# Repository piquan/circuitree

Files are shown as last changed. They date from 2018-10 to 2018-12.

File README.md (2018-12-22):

# Christmas tree circuit

Merry Christmas!  This is a fun little Christmas decoration that I
created as a gift to friends and family: a small circuit board in the
shape of a Christmas tree, with flashing lights and decorative
buttons, and a stand with has an optional nameplate.

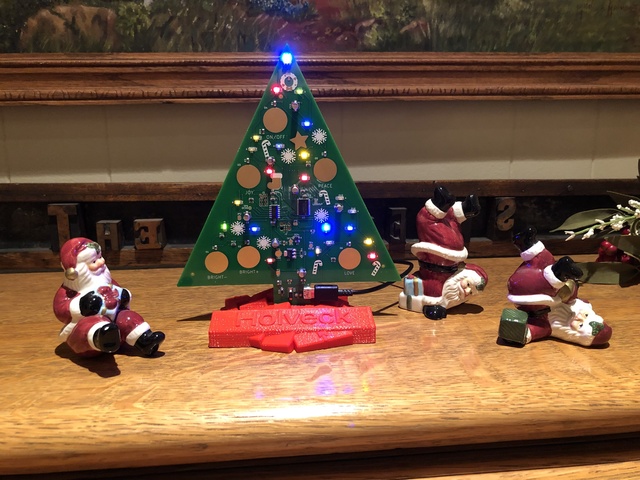
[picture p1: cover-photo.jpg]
Photo of the first production-complete Christmas tree decoration


I designed and programmed this from scratch for my closest friends and
family.  It’s taken me several months of engineering, but it’s been a
lot of fun, and I learned a lot of new things while I built it.  It’s
conceptually inspired by a similar circuit that Dad and I built in the
80s from a magazine article, but this circuit uses completely
different modern technology.  I sent my blueprints to [Macrofab, a
factory in Houston](https://macrofab.com/) to create the circuit
boards, and to [Jinxbot, a one-man 3D printing company in Mountain
View](https://jinxbot.com/) to create the stands.  I hand-programmed
and signed each circuit board.  In the four months I spent creating
this, I went through three revisions of the circuit board (plus
several smaller test designs), four revisions of the stand, and
hundreds of revisions of the program.  I hope you enjoy the Christmas
lights in your home as much as I’ve enjoyed creating it!

# Contributing

The entire project is open-source; you're encouraged to modify and
improve it.  Many of my friends are makers, so I want to make sure
that they can have extra fun by reading the details.  The project is
controlled by an ATtiny84A, so you can edit and upload the code right
from the Arduino IDE!  The firmware, debugging device, schematics, PCB
design, and decorative artwork is all in GitHub.

If you just want to look at the schematics and don't have KiCAD, you
can go to the "releases" tab in GitHub and download a zip file with
PDFs of the schematic and PCB, Gerber files for the PCB, .hex files
for the firmware, and .stl and .png files of the stand.

For technical documentation, visit the wiki.  There are notes there
about design decisions I've made, how to reprogram the Christmas tree,
and other useful information for makers.

Contributions are very welcome!  The best way to contribute is to open
a pull request or issue on GitHub.

# Credits

The schematic, PCB layout, decorative artwork, and firmware were all
designed by Joel Holveck.

The tlc5947.h LED driver controller library was originally written by
Limor Fried/Ladyada for Adafruit Industries, at
<https://github.com/adafruit/Adafruit_TLC5947/>.  The version included
here has several changes to use less memory, because of the needs of
the ATtiny environment.  I used Adafruit products (such as the
[TLC5947 breakout board](https://www.adafruit.com/product/1429)
extensively during the development of this project, and am very
grateful both for their product line and open-source contributions.

The capsense.h capacitive touch sensor library was inspired by the
library created by Paul Bagder as maintained by Paul Stoffregen, at
<https://github.com/PaulStoffregen/CapacitiveSensor/>.  The
implementation here is completely new, but borrows several ideas from
the Badger/Stoffregen library.  The Badger/Stoffregen capacitive touch
library is a very simple, straightforward capacitive touch sensing
library; seeing the way it was used helped convince me that the design
was viable.

# License

This project is copyright 2018 by Joel Ray Holveck.  All rights
reserved.

Different parts of this project are licensed differently; the licenses
are in the individual directories.  Generally, firmware is under
GPLv3, the PCB is under the CERN OHL, and the decorative artwork is
under CC-BY-SA.

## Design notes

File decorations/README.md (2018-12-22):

These are the original SVGs I used to create the decorative artwork on
the PCB.  This includes elements such as the snowflakes, wreath, etc.

Most of the decorations were created as svgs, exported as pngs,
imported to KiCad as mods, and then hand-edited to adjust layers.  I
haven't documented this process yet; please open an issue on GitHub if
you need information on how I did this.

My signature was not silkscreened; I hand-signed each board using a
Sharpie silver paint pen (34968PP).  The area of the PCB I signed was
deliberately cleared of vias (the only gaps in the silkscreen on the
back), so that the paint wouldn't conduct inadvertently.  My own
testing with the paint indicated that it's not conductive, but I still
wanted to avoid possible long-term corrosion or other issues.

The files in this directory are licensed under a Creative Commons
Attribution-ShareAlike 4.0 International License.  To view the
license, please visit http://creativecommons.org/licenses/by-sa/4.0/

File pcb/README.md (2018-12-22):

# PCB files

These are the files for the electrical schematic and PCB.

These files are in KiCAD format.  If you check out this directory, you
should be able to open christmas-tree.pro in KiCAD to see the
schematic and PCB layout.

The decorative artwork (and a few custom footprints) are included in
the christmas-tree.pretty directory.  The original SVG files used to
produce the decorative artwork are in the GitHub repository in the
decorations subdirectory.

If you just want to view the schematics or PCB layout files, they are
available in PDF format in the [release
ZIP](https://github.com/piquan/christmas-tree/releases/download/r4.0/Christmas-Tree-r4.zip).

The bill of materials is not included in my KiCAD files.  The BOM I
actually used is
[in the wiki](https://github.com/piquan/christmas-tree/wiki/Bill-of-materials).
That wiki page also includes a few notes about why I chose particular
components, but I don't yet have full documentation about the
components' design constraints.

# License

Copyright (C) 2018 Joel Ray Holveck.  All rights reserved.

This circuit is licensed under the CERN OHL, version 1.2.  The full
license is available in LICENSE.txt.  If you wish to distribute a
modified design, please update CHANGES.txt accordingly.

The requirements of section 3.1 of the CERN OHL require you to
maintain my original copyright and URL on the silkscreen of the PCB.
If you want a special exemption from these requirements, and your
modified PCB will include a clear traceable path to the original
project, I might approve a change to this text.  (For instance,
forking my GitHub project and changing the URL to your fork is likely
to be okay.)  In this case, contact me to request an excemption.

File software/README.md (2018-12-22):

# Firmware to program and control the Christmas tree circuit

This contains two programs: the christmas-tree subdirectory contains
the actual firmware to be uploaded to the tree; it also contains a
script to upload the firmware and program the fuses.  The spi-slave
subdirectory contains a program used to read the serial debugging I/O
(see the wiki for more details).

Copyright (C) 2018 Joel Ray Holveck

This program is free software: you can redistribute it and/or modify
it under the terms of the GNU General Public License as published by
the Free Software Foundation, either version 3 of the License, or
(at your option) any later version.

This program is distributed in the hope that it will be useful,
but WITHOUT ANY WARRANTY; without even the implied warranty of
MERCHANTABILITY or FITNESS FOR A PARTICULAR PURPOSE.  See the
GNU General Public License for more details.

You should have received a copy of the GNU General Public License
along with this program.  If not, see <https://www.gnu.org/licenses/>.

Additionally, tlc5947.h may also be copied under the terms of the
3-clause BSD license.  The license terms are in that file.

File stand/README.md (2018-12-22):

# Stand

The stand included with this project is 3d-printed, and designed in
OpenSCAD.

Many recipients have households with a common family name; for these,
the stand has a nameplate.  The stands I gave to some recipients (such
as families with children from a previous marriage) do not have
nameplates.  These are all generated from a common OpenSCAD file.

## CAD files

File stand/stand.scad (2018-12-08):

// You can set a name to have a personalized name plaque.  You can also
// set this on the command line with '-Dname="foo"', which will override
// this value.
name="";
bxr=1;                          // Box rounding

module gift(dx, dy, dz, x, y, z, tx, ty, tz, ribbonside=3) {
     // Prevent voids under boxes by extending them to the table.
     // Where this causes visible artifacts, it's best to make the box
     // taller.
     // This is the convex hull formed by (1) the box's bottom surface
     // and (2) the box's bottom surface projected on the xy plane.
     hull() {
          linear_extrude(height=0.1) projection()
               translate([x, y, z+(dz/2)-0.5]) rotate([tx, ty, tz]) hull() {
               translate([dx/2-bxr, dy/2-bxr, -dz/2+bxr]) sphere(r=bxr);
               translate([dx/2-bxr, -dy/2+bxr, -dz/2+bxr]) sphere(r=bxr);
               translate([-dx/2+bxr, dy/2-bxr, -dz/2+bxr]) sphere(r=bxr);
               translate([-dx/2+bxr, -dy/2+bxr, -dz/2+bxr]) sphere(r=bxr);
          }
          translate([x, y, z+(dz/2)-0.5]) rotate([tx, ty, tz]) hull() {
               translate([dx/2-bxr, dy/2-bxr, -dz/2+bxr]) sphere(r=bxr);
               translate([dx/2-bxr, -dy/2+bxr, -dz/2+bxr]) sphere(r=bxr);
               translate([-dx/2+bxr, dy/2-bxr, -dz/2+bxr]) sphere(r=bxr);
               translate([-dx/2+bxr, -dy/2+bxr, -dz/2+bxr]) sphere(r=bxr);
          }
     }
     translate([x, y, z+(dz/2)-0.5]) rotate([tx, ty, tz]) {
          // Box
          //cube([dx, dy, dz], center=true);
          // We actually use the hull of spheres for the box to prevent
          // lots of sharp 90deg corners.
          hull() {
               translate([dx/2-bxr, dy/2-bxr, dz/2-bxr]) sphere(r=bxr);
               translate([dx/2-bxr, dy/2-bxr, -dz/2+bxr]) sphere(r=bxr);
               translate([dx/2-bxr, -dy/2+bxr, dz/2-bxr]) sphere(r=bxr);
               translate([dx/2-bxr, -dy/2+bxr, -dz/2+bxr]) sphere(r=bxr);
               translate([-dx/2+bxr, dy/2-bxr, dz/2-bxr]) sphere(r=bxr);
               translate([-dx/2+bxr, dy/2-bxr, -dz/2+bxr]) sphere(r=bxr);
               translate([-dx/2+bxr, -dy/2+bxr, dz/2-bxr]) sphere(r=bxr);
               translate([-dx/2+bxr, -dy/2+bxr, -dz/2+bxr]) sphere(r=bxr);
          }
          // Bow body
          translate([0, 0, dz/2+.25]) hull() {
               translate([-.5, -.5, 0]) sphere(r=0.5);
               translate([-.5, .5, 0]) sphere(r=0.5);
               translate([.5, -.5, 0]) sphere(r=0.5);
               translate([.5, .5, 0]) sphere(r=0.5);
          }
          // Bow ribbons
          bowrot = (ribbonside >= 4 ? 90 : 0);
          rotate([0, 0, bowrot]) translate([0, 0, dz/2]) hull() {
               translate([-2, -2, 0.5]) sphere(r=0.25);
               translate([-2, 2, 0.5]) sphere(r=0.25);
               translate([-2, -2, 0]) sphere(r=0.25);
               translate([-2, 2, 0]) sphere(r=0.25);
               sphere(r=0.5);
          }
          rotate([0, 0, bowrot]) translate([0, 0, dz/2]) hull() {
               translate([2, -2, 0.25]) sphere(r=0.25);
               translate([2, 2, 0.25]) sphere(r=0.25);
               translate([2, -2, 0]) sphere(r=0.25);
               translate([2, 2, 0]) sphere(r=0.25);
               sphere(r=0.5);
          }
          // Box ribbons
          if (ribbonside == 1 || ribbonside == 3 ||
              ribbonside == 5 || ribbonside == 7) {
               hull() {
                    translate([dx/2, .5, dz/2]) sphere(r=0.25);
                    translate([dx/2, -.5, dz/2]) sphere(r=0.25);
                    translate([-dx/2, .5, dz/2]) sphere(r=0.25);
                    translate([-dx/2, -.5, dz/2]) sphere(r=0.25);
                    translate([dx/2, .5, -dz/2]) sphere(r=0.25);
                    translate([dx/2, -.5, -dz/2]) sphere(r=0.25);
                    translate([-dx/2, .5, -dz/2]) sphere(r=0.25);
                    translate([-dx/2, -.5, -dz/2]) sphere(r=0.25);
               }
          }
          if (ribbonside == 2 || ribbonside == 3 ||
              ribbonside == 6 || ribbonside == 7) {
               hull() {
                    translate([.5, dy/2, dz/2]) sphere(r=0.25);
                    translate([.5, -dy/2, dz/2]) sphere(r=0.25);
                    translate([-.5, dy/2, dz/2]) sphere(r=0.25);
                    translate([-.5, -dy/2, dz/2]) sphere(r=0.25);
                    translate([.5, dy/2, -dz/2]) sphere(r=0.25);
                    translate([.5, -dy/2, -dz/2]) sphere(r=0.25);
                    translate([-.5, dy/2, -dz/2]) sphere(r=0.25);
                    translate([-.5, -dy/2, -dz/2]) sphere(r=0.25);
               }
          }
     }
}

// This is an approximation of the desired shape.  Use it with % for debugging.
module approximation() {
     intersection() {
          // This sphere is designed so that it's 100mm at the z=0
          // plane, and 10mm high.  Solving
          // (100/2)^2 + (r-10)^2 = r^2 gives r=130.
          translate([0, 0, -120]) sphere(r=130);
          // Cut it off at the table.
          translate([-51, -51, 0]) cube([102, 102, 20], center=false);
     }
}
//%approximation();

module smallest() {
     // This is a small section to make sure that there aren't
     // critical gaps in the area that prevent it from functioning as
     // a support base.
     intersection() {
          // This sphere is designed so that it's 80mm at the z=0
          // plane, and 8mm high.  Solving
          // (80/2)^2 + (r-8)^2 = r^2 gives r=104.
          translate([0, 0, -96]) sphere(r=104);
          // Cut it off at the table.
          translate([-51, -51, 0]) cube([102, 102, 20], center=false);
     }
}

// Negative elements
module keepout() {
     // A bit of clearance for the board's components etc
     translate([-9, -4, 10]) cube([18, 5, 10], center=false);
}
module slot() {
     // Slot for the board to sit in
     translate([0, 0, 8]) cube([26.75, 2, 20], center=true);
}
module table() {
     // Flat bottom for the table or other surface
     translate([-100, -100, -50]) cube([200, 200, 50], center=false);
}
module usbchan() {
     // Channel for the USB connector.  Assume the USB shroud goes 2mm
     // on either side of the connector's footprint edge.  The
     // connector is 14mm from the bottom of the board, which is
     // 2mm from the table (see slot_struts).  That means the channel
     // starts 14mm from the table.
     // The connector is 9mm wide, so with margins use 13mm.
     translate([10, -4, 14]) {
          cube([60, 8, 13]);
     }
}
%usbchan();

module slot_struts() {
     // Small struts along the bottom for the board to sit on
     // If you move these, fix usbchan() accordingly.
     translate([-5, 0, 1]) cube([2, 3, 2], center=true);
     translate([5, 0, 1]) cube([2, 3, 2], center=true);
}

module gifts() {
     scale(1.2) {
          //   SIZE                POSITION            ROTATION
          gift(21, 19, 5,          10, 10, 2.5,        5, 10, 15,     0);
          gift(19, 20, 6,          8, -11, 3,          10, 5, 0,      5);
          gift(13, 8, 5,           -13, 5, 4,          -5, -10, 15,   2);
          gift(12, 12, 5,          -8, 17, 4,          -5, -5, -5,    8);
          gift(17, 17, 6,          -10, -12, 5,        10, -15, -12,  3);
          gift(8, 12, 8,           2, 18, 4,           -20, -15, 10,  6);
          gift(24, 6, 3,           20, 1, 4,           -20, 15, 10,   2);
          gift(15, 20, 2,          -25, -8, 3,         15, -15, 5,    3);
          gift(16, 19, 7,          -22, 10, 2.5,       -15, -15, 5,   4);
          gift(21, 17, 8,          -20, -25, -1,        15, -10, -35,  6);
          gift(10, 25, 6,          -35, 0, 1,          0, -20, 10,    2);
          gift(12, 20, 3,          30, -15, 2.5,       5, 10, -20,    8);
          gift(15, 15, 5,          20, -10, 6,         5, 10, 60,     0);
          gift(20, 20, 3,          13, -22, 6,         10, 10, 10,    6);
          gift(30, 10, 7,          15, -35, 0,         15, -5, 15,    2);
          gift(15, 25, 6,          -5, -30, 2,         15, -5, -20,   8);
          gift(20, 10, 4,          -5, 10, 10,         10, -5, -45,   3);
          gift(20, 10, 3,          30, 15, 2,          -20, 5, -45,   5);
          gift(11, 16, 4,          25, 12, 5,          0, 15, 35,     2);
          gift(11, 26, 6,          12, 24, 3,          -20, 5, -5,    8);
          gift(14, 14, 6,          34, 0, 1,           -10, 25, 0,    0);
          gift(24, 8,  8,          0, 34, 1,           -25, -10, 0,   5);
          gift(17, 13, 4,          0, 24, 5,           -20, -5, 10,   2);
          gift(19, 20, 6,          -19, 22, 3,         -35, -5, 40,   8);
          gift(15, 15, 8,          25, 28, 0,          0, 0, 45,      4);
          gift(10, 15, 8,          -32, -16, 0,        0, 0, 30,      4);
          gift(15, 10, 8,          -32, 20, 0,         0, 0, 30,      2);
     }
}
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

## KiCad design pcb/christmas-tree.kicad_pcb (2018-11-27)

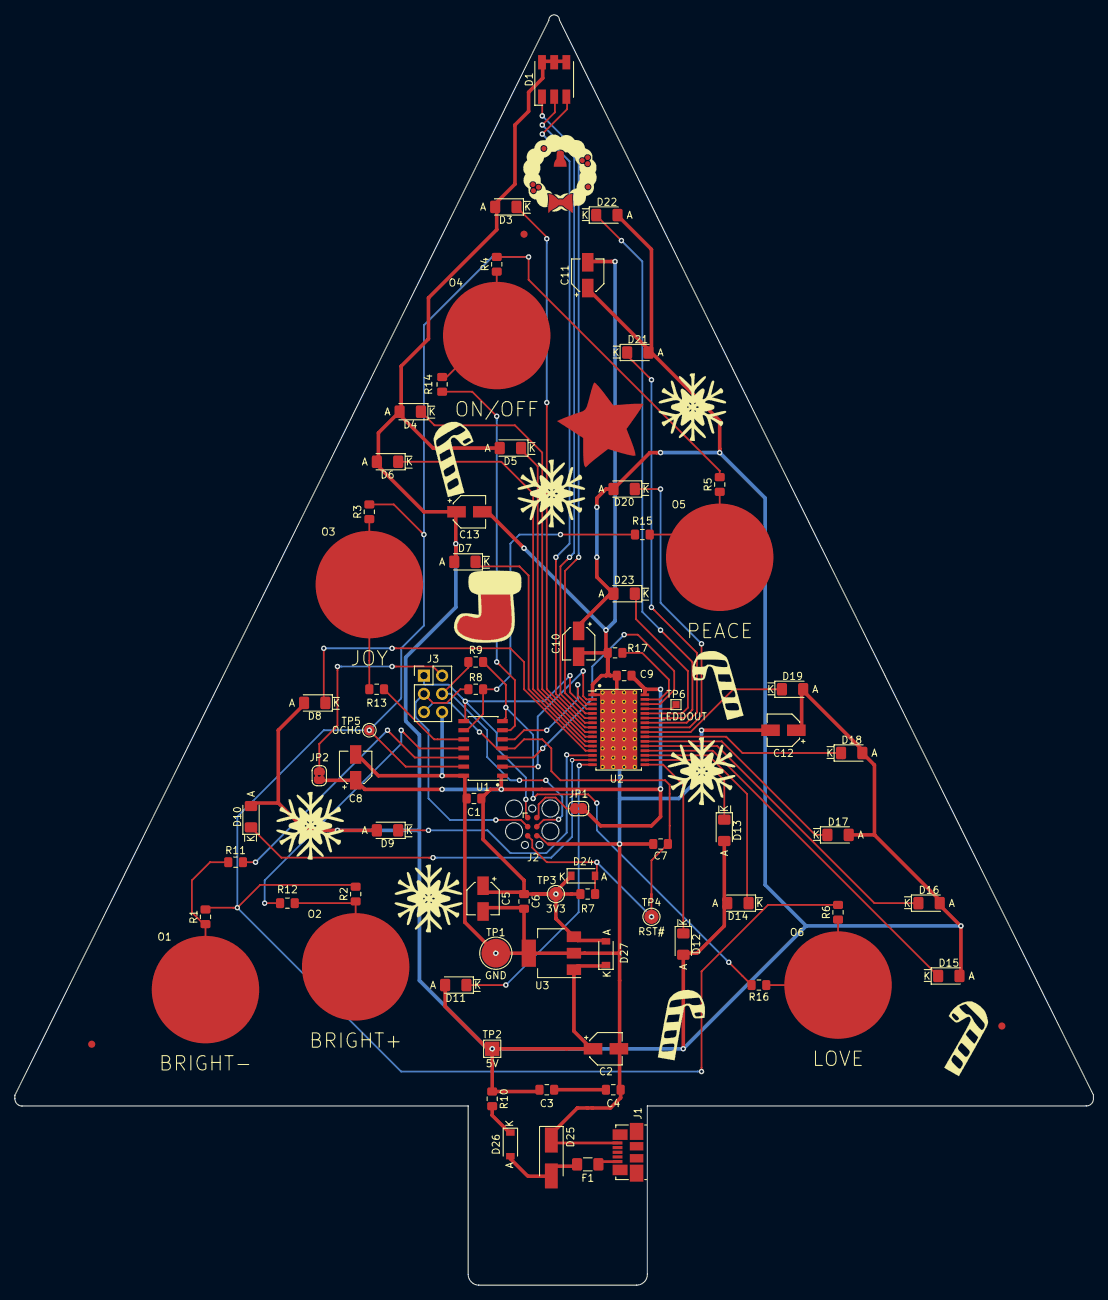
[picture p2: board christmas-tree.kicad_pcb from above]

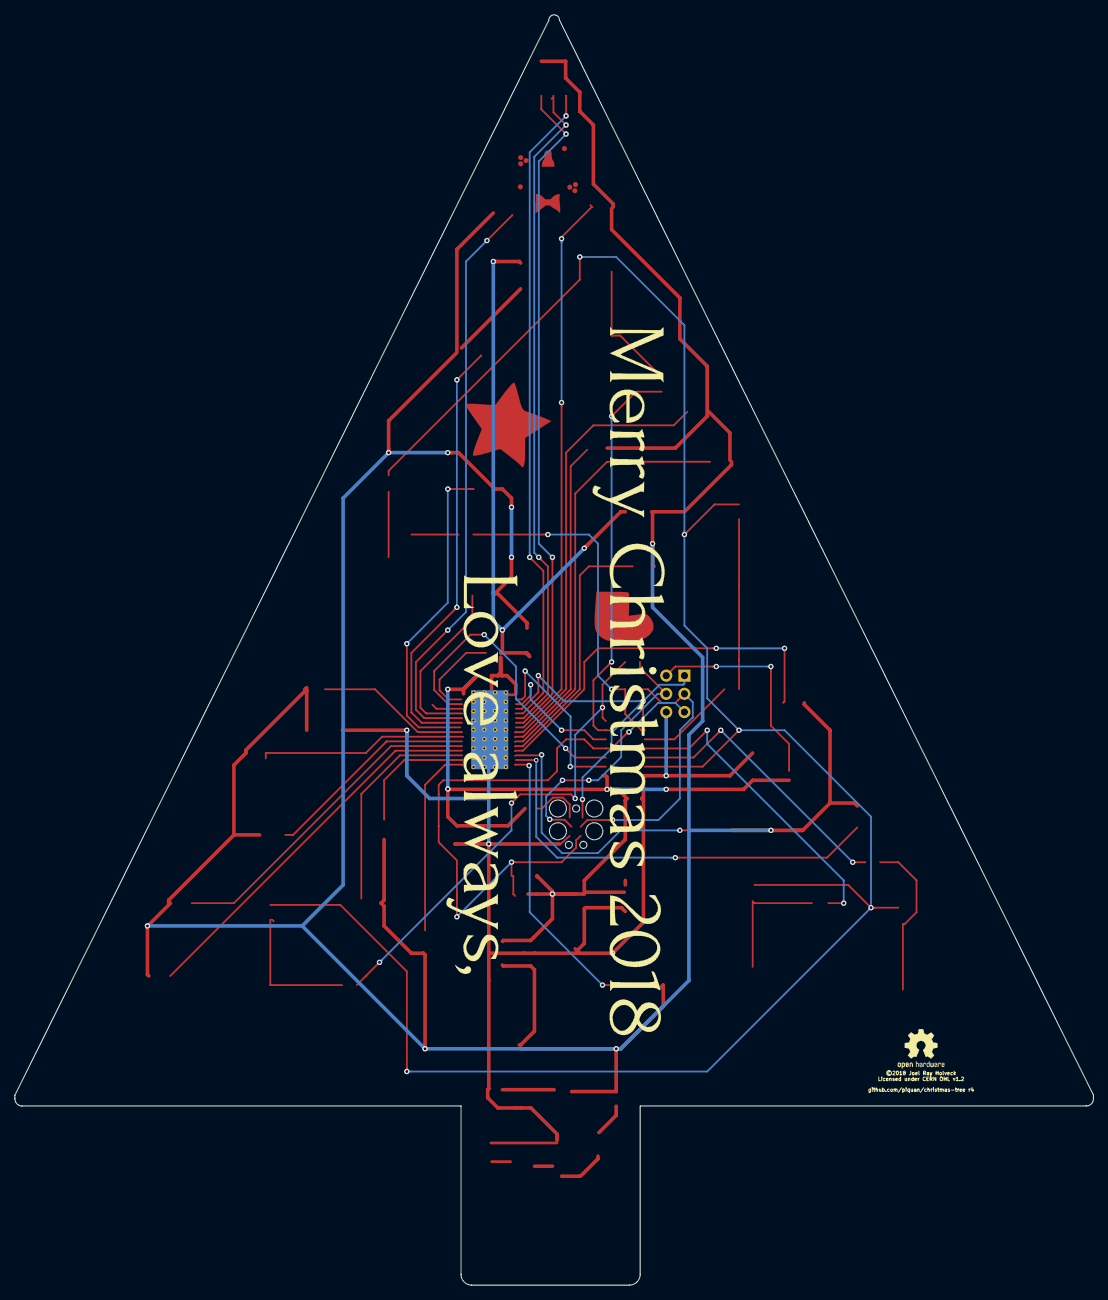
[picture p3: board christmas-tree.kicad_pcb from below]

Board: 2 copper layers, 150.5 x 177.2 mm, 95 parts (3 on the bottom side), 55 nets.

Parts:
C1, C9: 0.1uF; C_0805_2012Metric_Pad1.15x1.40mm_HandSolder
C2, C5, C8, C10, C11, C12, C13: 3.3uF; CP_Elec_4x5.4
C3, C4, C6, C7: DNP; C_0805_2012Metric_Pad1.15x1.40mm_HandSolder
D1: LED_RGB; LED_RGB_5050-6
D3, D7, D11, D15, D19, D23: LTST-C150KRKT; LED_1206_Wurth_AK
D4, D8, D12, D16, D20: LTST-C150KSKT; LED_1206_Wurth_AK
D5, D9, D13, D17, D21: LTST-C150TBKT; LED_1206_Wurth_AK
D6, D10, D14, D18, D22: LTST-C150KGKT; LED_1206_Wurth_AK
D24, D26: MBR0520L; D_SOD-123_AK
D25: SMAJ7.0CA; D_SMA_Handsoldering
D27: DNP; D_SOD-123_AK
DORN1: SYM_Arrow45_Tiny; star
DORN2: SYM_Arrow45_Tiny; stocking
DORN3, DORN5: SYM_Arrow45_Tiny; candy-cane
DORN4, DORN6: SYM_Arrow45_Tiny; candy-cane-mirror
DORN7, DORN8, DORN9, DORN10, DORN11: SYM_Arrow45_Tiny; snowflake
DORN12: SYM_Arrow45_Tiny; OSHW-Logo2_7.3x6mm_SilkScreen
DORN13: SYM_Arrow45_Tiny; wreath
F1: 500mA; Fuse_1206_3216Metric_Pad1.42x1.75mm_HandSolder
FID1, FID2, FID3: SYM_Arrow45_Tiny; Fiducial_1mm_Dia_2.54mm_Outer_CopperTop
J1: USB_B_Micro; USB_Micro-B_Molex_47346-0001
J2: TC2030; Tag-Connect_TC2030-IDC-FP_2x03_P1.27mm_Vertical
J3: AVR-ISP-6; PinHeader_2x03_P2.54mm_Vertical
JP1: JCPWR; SolderJumper-2_P1.3mm_Bridged2Bar_RoundedPad1.0x1.5mm
JP2: ISPPWR; SolderJumper-2_P1.3mm_Bridged2Bar_RoundedPad1.0x1.5mm
LOGO1: Logo_Merry_Christmas; merry-christmas
LOGO2: Logo_Merry_Christmas; love-always
O1: BRIGHT-; TestPoint_Pad_D15.0mm
O2: BRIGHT+; TestPoint_Pad_D15.0mm
O3: JOY; TestPoint_Pad_D15.0mm
O4: ON/OFF; TestPoint_Pad_D15.0mm
O5: PEACE; TestPoint_Pad_D15.0mm
O6: LOVE; TestPoint_Pad_D15.0mm
R1, R2, R3, R4, R5, R6: 1M; R_0805_2012Metric_Pad1.15x1.40mm_HandSolder
R7: 10K; R_0805_2012Metric_Pad1.15x1.40mm_HandSolder
R8, R9: 100; R_0805_2012Metric_Pad1.15x1.40mm_HandSolder
R10: 0; R_0805_2012Metric_Pad1.15x1.40mm_HandSolder
R11, R12, R13, R14, R15, R16: 50; R_0805_2012Metric_Pad1.15x1.40mm_HandSolder
R17: 2.7K; R_0805_2012Metric_Pad1.15x1.40mm_HandSolder
TP1: GND; TestPoint_Pad_D4.0mm
TP2: 5V; TestPoint_Pad_2.0x2.0mm
TP3: 3V3; TestPoint_Pad_D2.0mm
TP4: RST#; TestPoint_Pad_D2.0mm
TP5: OCHG; TestPoint_Pad_D1.5mm
TP6: LEDDOUT; TestPoint_Pad_1.0x1.0mm
U1: ATtiny84A-20SSU; SOIC-14_3.9x8.7mm_P1.27mm
U2: TLC5947DAP; HTSSOP-32-1EP_6.1x11mm_P0.65mm_EP5.2x11mm_Mask4.11x4.36mm_T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
U3: LT1129CST-3.3; SOT-223-3_TabPin2

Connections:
+3V3: C1.2, C5.1, C6.1, C8.1, C9.2, D24.1, D27.2, JP1.1, JP2.1, R7.1, TP3.1, U1.1, U2.32, U3.3
+5V: C2.1, C3.1, C10.1, C11.1, C12.1, C13.1, D1.4, D1.5, D1.6, D3.2, D4.2, D5.2, D6.2, D7.2, D8.2, D9.2, D10.2, D11.2, D12.2, D13.2, D14.2, D15.2, D16.2, D17.2, D18.2, D19.2, D20.2, D21.2, D22.2, D23.2, D27.1, R10.1, TP2.1, U3.1
/BLANK: U1.2, U2.2
/IREF: R17.1, U2.31
/ISPMOSI: J2.4, J3.4, R9.1
/ISPSCK: J2.3, J3.3, R8.1
/LEDCLK: U1.5, U2.3
/LEDDOUT: TP6.1, U2.29
/MISO: J2.1, J3.1, U1.8, U2.4
/MOSI: R9.2, R16.2, U1.7
/O1S: R11.2, U1.12
/O2S: R12.2, U1.11
/O3S: R13.2, U1.10
/O4S: R14.2, U1.6
/OCHG: R1.2, R2.2, R3.2, R4.2, R5.2, R6.2, TP5.1, U1.13
/RST#: C7.1, D24.2, J2.5, J3.5, R7.2, TP4.1, U1.4
/SCK: R8.2, R15.2, U1.9
/XLAT: U1.3, U2.30
GND: C1.1, C2.2, C4.2, C5.2, C6.2, C7.2, C8.2, C9.1, C10.2, C11.2, C12.2, C13.2, D25.1, J1.5, J2.6, J3.6, R17.2, TP1.1, U1.14, U2.1, U2.33, U3.2
unnamed: C3.2, C4.1
unnamed: D1.1, U2.5
unnamed: D1.2, U2.6
unnamed: D1.3, U2.7
unnamed: D3.1, U2.8
unnamed: D4.1, U2.9
unnamed: D5.1, U2.10
unnamed: D6.1, U2.11
unnamed: D7.1, U2.12
unnamed: D8.1, U2.13
unnamed: D9.1, U2.14
unnamed: D10.1, U2.15
unnamed: D11.1, U2.16
unnamed: D12.1, U2.17
unnamed: D13.1, U2.18
unnamed: D14.1, U2.19
unnamed: D15.1, U2.20
unnamed: D16.1, U2.21
unnamed: D17.1, U2.22
unnamed: D18.1, U2.23
unnamed: D19.1, U2.24
unnamed: D20.1, U2.25
unnamed: D21.1, U2.26
unnamed: D22.1, U2.27
unnamed: D23.1, U2.28
unnamed: D25.2, D26.2, F1.1
unnamed: D26.1, R10.2
unnamed: F1.2, J1.1
unnamed: J2.2, JP1.2
unnamed: J3.2, JP2.2
unnamed: O1.1, R1.1, R11.1
unnamed: O2.1, R2.1, R12.1
unnamed: O3.1, R3.1, R13.1
unnamed: O4.1, R4.1, R14.1
unnamed: O5.1, R5.1, R15.1
unnamed: O6.1, R6.1, R16.1

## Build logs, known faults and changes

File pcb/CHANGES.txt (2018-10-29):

If you wish to change and redistribute a product based on this design, please modify this file in the modified distribution describing your changes.

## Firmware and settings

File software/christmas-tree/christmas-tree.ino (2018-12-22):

// christmas-tree.ino - Firmware for a Christmas decoration
// Copyright (C) 2018 Joel Ray Holveck
//
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

//#define NDEBUG 1

#include <avr/boot.h>
#include <avr/wdt.h>
#include <EEPROM.h>

#pragma GCC diagnostic warning "-Wall"
#pragma GCC diagnostic warning "-Wextra"

#ifdef NDEBUG
#define assert(e) do {} while (0)
#else
void AssertFail(int lineno);
#define assert(e) ((e) ? (void)0 : AssertFail(__LINE__))
#endif

// I could make this inherit from Print to get printf, etc.  But the
// decimal print routines take up too much flash space (about 300
// bytes), so I print in hex, which is much cheaper.
class CTDebugger final {
#ifdef NDEBUG
 public:
  void write(uint8_t) {}
  template<typename T> void print(T) {}
  template<typename T> void println(T) {}
#else
 private:
  const char hexdigs[16] = {'0', '1', '2', '3', '4', '5', '6', '7',
                            '8', '9', 'a', 'b', 'c', 'd', 'e', 'f'};
  void PrintByte(uint8_t val) {
    write(hexdigs[val >> 4]);
    write(hexdigs[val & 0x0f]);
  }
 public:
  void write(uint8_t);
  void print(uint8_t val) {
    PrintByte(val);
  }
  void print(uint16_t val) {
    PrintByte(val >> 8);
    PrintByte(val);
  }
  void print(uint32_t val) {
    PrintByte(val >> 24);
    PrintByte(val >> 16);
    PrintByte(val >> 8);
    PrintByte(val);
  }
  void print(const char* val) {
    while (*val) {
      write(*(val++));
    }
  }
  void print(int8_t val) {
    if (val < 0) {
      write('-');
      print(static_cast<uint8_t>(-val));
    } else {
      print(static_cast<uint8_t>(val));
    }
  }
  void print(int16_t val) {
    if (val < 0) {
      write('-');
      print(static_cast<uint16_t>(-val));
    } else {
      print(static_cast<uint16_t>(val));
    }
  }
  void print(int32_t val) {
    if (val < 0) {
      write('-');
      print(static_cast<uint32_t>(-val));
    } else {
      print(static_cast<uint32_t>(val));
    }
  }
  void print(float val);
  void print(double val) { print(static_cast<float>(val)); }
  void println() {
    write('\r');
    write('\n');
  }
  template<typename T> void println(T val) {
    print(val);
    println();
  }
 private:
  void Clock(bool val);
#endif
} Debugger;

//#define DO_TRACE 1
#ifdef DO_TRACE
#define TRACELINE(arg) do {                             \
    Debugger.write('t'); Debugger.println(__LINE__);    \
  } while (0)
#else
#define TRACELINE(arg) do {} while (0)
#endif

#include "capsense.h"
#include "tlc5947.h"

// This is smaller than the built-in memset.
void MyMemSet(void* addr, uint8_t size, uint8_t val) {
  for (uint8_t i = 0; i < size; i++) {
    static_cast<char*>(addr)[i] = val;
  }
}

// The Arduino doesn't have a built-in random float function, so I
// have this instead.  It ain't perfect by a long shot, but it works
// for my needs.
float RandomFloat(float max) {
  return (max * static_cast<float>(random()) / static_cast<float>(LONG_MAX));
}

constexpr uint16_t kNumGpios = 10;  // Is this in a #defined constant?

constexpr float kBrightChangeRate = 1.0 / 32;

// Note that CANARY takes about 132 bytes.
#define CANARY 1
constexpr uint8_t kStackCanaryVal = 105;
constexpr uint8_t kStackCanarySweepFreq = 64;

// Regarding kCsSamps: Larger is more stable but slower.  The speed
// also depends on the capacitance present; lower capacitance resolves
// more quickly.  With four sensors (well, as of this writing, one
// sensor being probed 4 times), a 1M resistor, and a 3.3v supply,
// kCsSamps=16 samples gives a loop rate of about 42 Hz when there's
// no finger present, and about 20 Hz when all sensors are triggered.
constexpr uint8_t kCsSamps = 16;

// When tuning kCsThres, make sure your hand isn't over the laptop!
constexpr unsigned int kCsThres = kCsSamps * 6;
constexpr unsigned int kCsThrL = kCsThres / 2;
constexpr unsigned int kCsThrH = kCsThres * 3 / 2;

// For mappings between package pin numbers and GPIO pin numbers,
// see http://highlowtech.org/?p=1695 specifically
// http://highlowtech.org/wp-content/uploads/2011/10/ATtiny44-84.png
constexpr uint8_t kPinCsChg = 0;
constexpr uint8_t kPinCsO1S = 1;
constexpr uint8_t kPinCsO2S = 2;
constexpr uint8_t kPinCsO3S = 3;
constexpr uint8_t kPinCsO4S = 7;
constexpr uint8_t kPinCsO5S = 4;
constexpr uint8_t kPinCsO6S = 6;

// We use the same pin for kPinDbgMosi as kPinLedMosi.
// This is the MISO (not MOSI) line on the ICSP header.
constexpr uint8_t kPinDbgMosi = 5;
constexpr uint8_t kPinDbgSclk = 4;

// The debug protocol seems stable at about 100uS hold time in initial
// experiments.  It may be related to the time I spend on the slave
// doing serial writes, since my writes are amplified a lot.  I might
// also try a direct port read in the slave, which is about 25x
// faster.  Note that this is only the hold time for high or low; the
// total clock period is about twice this.  Note that the debug host
// will resync if there's no clock for 10ms, to make sure it doesn't
// get its bits out of phase.
constexpr unsigned int kDbgClkHoldMicros = 250;

constexpr uint8_t kPinLedMosi = 5;
constexpr uint8_t kPinLedSclk = 8;
constexpr uint8_t kPinLedLat = 9;
constexpr uint8_t kPinLedBlank = 10;

constexpr int kPostFailBlinks = 3;

TLC5947<1,                   // Number of drivers
        kPinLedSclk,         // SPI clock pin
        kPinLedMosi,         // SPI data pin
        kPinLedLat> leds;    // Latch pin

#define LED_PHASE1 0
#define LED_PHASE2 1
#define LED_PHASE3 2
constexpr float kLoveStarMaxRamp = 0.75;
constexpr float kPhaseIncrPeace = 0.005;
constexpr float kPhaseIncr = 0.05;
//#define LED_SCHMITT 3
//#define LED_COUNT0 3  // Note that COUNT0 == Q
//#define LED_COUNT1 4
//#define LED_COUNT2 5
//#define LED_COUNT3 6
//#define LED_Q 9
//#define LED_NQ 10
//#define LED_CYCLE 11
//#define LED_CAP 12
#define LED_METER_START 15
constexpr uint16_t kLedMeterCount = 5;
constexpr long kLedMeterMax = kCsThres * 2;

constexpr int kNumLedColors = 4;
// The instance, and the referenced arrays, must be in PROGMEM.
class LedStars {
 private:
  class PgmArrayReader {
   public:
    explicit PgmArrayReader(uint8_t const* pgm_array_ptr)
        : pgm_array_ptr_(pgm_array_ptr) {}
    explicit PgmArrayReader(uint8_t const* const* pgm_array_pgm_ptr)
        : pgm_array_ptr_(pgm_read_word(pgm_array_pgm_ptr)) {}
    uint8_t operator[] (size_t i) const {
      return pgm_read_byte(pgm_array_ptr_ + i);
    }
    PgmArrayReader& operator+=(size_t increment) {
      pgm_array_ptr_ += increment;
      return *this;
    }
   private:
    const uint8_t* pgm_array_ptr_;
  };

 public:
  void Setup() const {
    count_ = pgm_read_byte(&pgm_count_);
  }

  PgmArrayReader by_pos() const {
    return PgmArrayReader(&pgm_by_pos_);
  }
  PgmArrayReader by_color() const {
    return PgmArrayReader(&pgm_by_color_);
  }
  PgmArrayReader color_counts() const {
    return PgmArrayReader(pgm_color_counts_);
  }
  uint8_t Count() const {
    return count_;
  }

 public: // FIXME Make these private
  const uint8_t* pgm_by_pos_;
  const uint8_t* pgm_by_color_;
  const uint8_t pgm_color_counts_[kNumLedColors];
  const uint8_t pgm_count_;
  static uint8_t count_;  // Updated once at start of program
};

uint8_t LedStars::count_;

#ifndef NDEBUG
const uint8_t led_stars_dev_by_pos[] PROGMEM = {
  3, 4, 5, 6, 7, 8, 9, 10, 11, 12, 14, 13, 23, 20, 21, 22 };
const uint8_t led_stars_dev_by_color[] PROGMEM = {
  6, 10, 14, 22,  // green
  3, 7, 11, 23,   // red
  4, 8, 12, 20,   // yellow
  5, 9, 13, 21    // blue
};
constexpr LedStars led_stars_dev PROGMEM = {
  .pgm_by_pos_ = led_stars_dev_by_pos,
  .pgm_by_color_ = led_stars_dev_by_color,
  .pgm_color_counts_ = { 4, 4, 4, 4 },
  .pgm_count_ = 16,
};
#endif
const uint8_t led_stars_norm_by_pos[] PROGMEM = {
  3, 4, 5, 6, 7, 8, 9, 10, 11, 12, 14,
  13, 15, 16, 17, 18, 19, 23, 20, 21, 22 };
const uint8_t led_stars_norm_by_color[] PROGMEM = {
  6, 10, 14, 18, 22,    // green
  3, 7, 11, 15, 19, 23, // red
  4, 8, 12, 16, 20,     // yellow
  5, 9, 13, 17, 21,     // blue
};
constexpr LedStars led_stars_norm PROGMEM = {
  .pgm_by_pos_ = led_stars_norm_by_pos,
  .pgm_by_color_ = led_stars_norm_by_color,
  .pgm_color_counts_ = { 5, 6, 5, 5 },
  .pgm_count_ = 21,
};

#ifndef NDEBUG
const LedStars* led_stars;
#else
constexpr const LedStars* led_stars = &led_stars_norm;
#endif
constexpr int kNumLedStarsMax = led_stars_norm.pgm_count_;

// Constants for Peace and Love modes.
constexpr float kLedStarMinMotion = 0.005;
constexpr float kLedStarDeltaMotion = 0.01;
constexpr long kLedStarPeriod = 64;
constexpr long kLedStarBurstPeriod = 128;

#ifndef NDEBUG
bool dev_mode;
#endif
enum DisplayMode { kModeLove, kModePeace, kModeJoy } display_mode = kModeLove;
enum JoySubMode { kSubModeDoubleChase, kSubModeCylon, kSubModeCylonFill, 
                  kSubModeLast };
JoySubMode joy_sub_mode = kSubModeDoubleChase;

// FIXME Why are these separate from the top-level variables?
struct __attribute__ ((__packed__)) {
  bool uninitialized;  // Erased EEPROM reads as all 1s
  float bright_pct;
  DisplayMode display_mode;
  JoySubMode joy_sub_mode;
} persistent_data;
unsigned long update_persistent_data_at_millis = ULONG_MAX;

// We use the LED on the debugging dongle to tell us if we've ever
// gotten a high reading.  That lets me leave it alone for a long time
// and see if it ever got a false reading.  This tells us if we need
// to send the latch signal.  To prevent spamming the LED latch
// signal, but still let us reset it just by resetting the debug board,
// we only send it at most once per second.
unsigned long debug_led_latch_at_millis;
constexpr unsigned long kDbgLedLatchDelayMs = 1000;

uint16_t bright; // Calculated during startup
float bright_pct = 0.5;

void __attribute__((noinline)) TwinkleBool(uint16_t ledno, bool val) {
  // The twinkling of boolean outputs in debug mode is cute, but it takes
  // 90 bytes or so of code space.
#ifdef DO_TWINKLE_BOOL
  long delta = display_mode == kModeLove ? random(bright/128) : 0;
  // The "16 * delta" is because we totally ignore the gamma curve here.
  leds.setPWM(ledno, val ? bright - (16 * delta) : delta);
#else
  leds.setPWM(ledno, val ? bright : 0);
#endif
}

#ifndef NDEBUG
void __attribute__((noinline)) CTDebugger::Clock(bool val) {
  digitalWrite(kPinDbgSclk, val);
  delayMicroseconds(kDbgClkHoldMicros);
}
void CTDebugger::write(uint8_t byte) {
  pinMode(kPinDbgSclk, OUTPUT);
  for (int i = 0; i < 8; i++) {
    digitalWrite(kPinDbgMosi, byte & 0x80);
    byte <<= 1;
    Clock(true);
    Clock(false);
  }
}

// Takes about 186 bytes (if it's actually called)
void CTDebugger::print(float value_in) {
  union {
    // Essentially defines the IEEE 784-2008 binary16 layout
    struct {
      unsigned int significand: 10;
      unsigned int exponent: 5;
      unsigned int sign: 1;
    } bits;
    float flo;
  } value;
  value.flo = value_in;

  // Print the sign even if it's a NaN.  This saves some code space,
  // and also distinguishes between quiet (negative) and signaling
  // (positive) NaNs.
  if (value.bits.sign) {
    write('-');
  }
  
  // Check NaN and infinity
  if (value.bits.exponent == 0x1f) {
    if (value.bits.significand != 0) {
      print("nan");
    } else {
      print("inf");
    }
    return;
  }
  
  if (value.bits.exponent == 0) {
    write('0');
  } else {
    write('1');
  }
  write('.');

  print(value.bits.significand >> 2);
  print(value.bits.significand << 6);
  
  // We use 'x' to separate the significand from the exponent.  The
  // C++ %a modifier uses 'p', but it prints the exponent in decimal,
  // so we avoid that.
  write('x');
  int8_t norm_exponent = value.bits.exponent - 15;
  print(norm_exponent);
}
#endif

void DidFail(void) {
  // Use this if you want to halt the board after failures (e.g., during
  // overnight testing).
  //wdt_disable();
  //while(1);
}

#ifndef NDEBUG
void AssertFail(int lineno) {
  Debugger.write('A');
  Debugger.println(lineno);
  DidFail();
}
#endif

void PostFail(uint8_t code, uint8_t aux) {
  uint16_t combined_code = (aux << 8) | code;
  for (uint16_t i = 4; i < 20; i++) {
    leds.setPWM(i, combined_code & 1 ? leds.kPwmMax : 0);
    combined_code >>= 1;
  }
  digitalWrite(kPinLedBlank, LOW);

#ifndef NDEBUG
  Debugger.write('\x0c');
  Debugger.write('X');
  Debugger.print(code);
  Debugger.write(':');
  Debugger.println(aux);
  for (uint8_t i = 0; i < kPostFailBlinks; i++) {
    leds.setPWM(1, 0);  // Red LED
    leds.write();
    delay(1000);
    leds.setPWM(1, bright);
    leds.write();
    delay(1000);
  }
#endif
  DidFail();
}

class CapOrnament {
 public:
  CapOrnament(char name, uint16_t sense_pin) :
      cs_(sense_pin), name_(name), sense_pin_(sense_pin) {}
  bool level() const { return state_.level; };
  void set_led_diagnostic(bool d) { state_.led_diagnostic = d; }
  bool led_diagnostic() const { return state_.led_diagnostic; }
  bool offline() const { return state_.offline; }
  void set_offline(bool offline) { state_.offline = offline; }
  void Post(uint8_t code);
  bool SenseEdge();
  bool SenseLevel() { SenseEdge(); return level(); }
  static uint8_t count(void) { return count_; }
#ifndef NDEBUG
  static void SweepDbgSensor();
#endif

 private:
#ifndef NDEBUG
  static constexpr int kDbgSensorPinShift = 1;
  static constexpr uint16_t kDbgSensorSweepLength =
      kNumGpios << kDbgSensorPinShift;
  static uint8_t dbg_sensor_;
#endif
  static uint8_t count_;

  void PostOneWay(uint8_t code, bool value);
#ifndef NDEBUG
  bool Dbg() { return dbg_sensor_ == (sense_pin_ << kDbgSensorPinShift); }
#endif

  template<unsigned int threshold_l, unsigned int threshold_h>
  bool Schmitt(unsigned int input);
  bool CheckRisingEdge(bool input);

  CapacitiveSensor<kPinCsChg> cs_;
  char name_;
  uint8_t sense_pin_;
  struct {
    bool offline : 1;
    bool led_diagnostic : 1;
    bool level : 1;
  } state_;
};
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
void loop() {
  wdt_reset();
  static uint8_t loop_count;
  loop_count++;
#ifndef NDEBUG
  CapOrnament::SweepDbgSensor();
#endif

  bool bright_down_edge = csBrightDn.SenseEdge();
  bool bright_up_edge = csBrightUp.SenseEdge();
  bool bright_down_level = csBrightDn.level();
  bool bright_up_level = csBrightUp.level();
  if (bright_down_level || bright_up_level) {
    if (bright_down_edge)
      bright_pct -= kBrightChangeRate * 3;
    if (bright_down_level)
      bright_pct -= kBrightChangeRate;
    if (bright_up_edge)
      bright_pct += kBrightChangeRate * 3;
    if (bright_up_level)
      bright_pct += kBrightChangeRate;
    UpdateBrightnessFromPct();
    update_persistent_data_at_millis = millis() + 2000;
  }

  bool toggle_onoff = csOnOff.SenseEdge();
  if (toggle_onoff) {
    static bool blank_state = false;
    blank_state = !blank_state;
    digitalWrite(kPinLedBlank, blank_state);
    Debugger.println(blank_state ? 'o' : 'O');
  }

  bool gotLove = csLove.SenseEdge();
  bool gotJoy = csJoy.SenseEdge();
  bool gotPeace = csPeace.SenseEdge();

  // We always reset the display, even if we're in the right mode, to
  // give visual feedback to the user.  Otherwise, the user might
  // start fiddling with buttons by pressing the current mode and
  // think that the button does nothing.
  if (gotLove) {
    display_mode = kModeLove;
  } else if (gotPeace) {
    display_mode = kModePeace;
  } else if (gotJoy) {
    if (display_mode == kModeJoy) {
      joy_sub_mode = 
          static_cast<JoySubMode>(static_cast<int>(joy_sub_mode) + 1);
      if (joy_sub_mode == kSubModeLast) {
        joy_sub_mode = static_cast<JoySubMode>(0);
      }
    }
    display_mode = kModeJoy;
  }

  if (gotLove || gotPeace || gotJoy) {
    MyMemSet(&display_state, sizeof(display_state), 0);
#if 0  // This doesn't work yet
    if (display_mode != kModeJoy) {
      // Filling a float16 with the byte 0x38 works out to about .5;
      // the byte 0x21 is about 0.01.
      static_assert(sizeof(display_state.peace_love.star_brightness) ==
                    sizeof(display_state.peace_love.star_motion),
                    "size mismatch");
      for (uint8_t i = 0;
           i < sizeof(display_state.peace_love.star_brightness);
           i++) {
        static_cast<char*>(static_cast<void*>(&display_state.peace_love.star_brightness))[i] = 0x38;
        static_cast<char*>(static_cast<void*>(&display_state.peace_love.star_motion))[i] = 0x21;
      }
      MyMemSet(&display_state.peace_love.star_ramping_up,
               sizeof(display_state.peace_love.star_ramping_up),
               0x55);
    }
#endif
    persistent_data.display_mode = display_mode;
    persistent_data.joy_sub_mode = joy_sub_mode;
    update_persistent_data_at_millis = millis() + 2000;
  }

#ifdef LED_CYCLE
  if (dev_mode)
    leds.setPWM(LED_CYCLE, (loop_count & 1) ? 0 : bright);
#endif

  if (display_mode == kModeJoy) {
    auto by_pos = led_stars->by_pos();
    switch (joy_sub_mode) {
      case kSubModeDoubleChase:
        {
          for (uint16_t i = 0; i < led_stars->Count(); i++) {
            uint8_t i_8bit = i * 256 / led_stars->Count();
            // Compute the absolute value of i_8bit - cycle
            uint8_t mag_major = i_8bit - display_state.joy.cycle;
            if (mag_major & 0x80)
              mag_major = ~mag_major;
            uint8_t mag_minor = i_8bit - display_state.joy.cycle_minor;
            if (mag_minor & 0x80)
              mag_minor = ~mag_minor;
            // mag_major and mag_minor now hold 7 bits of data each.  It's
            // a little tricky to do gamma correction in integer space
            // without losing too much precision.  Unfortunately, 32-bit
            // arithmetic is quite expensive on an AVR, and 16-bit only
            // slightly less so.  Our inputs are only 8 bits, so we're ok
            // with some loss of magnitude precision during this stage,
            // as long as we don't lose it all up-front.
            uint8_t bright_8bit = bright / 16;           // 0-255
            uint16_t mag_14bit = mag_major * mag_minor;  // 0-16129
            uint16_t mag_gamma = mag_14bit / 64;         // 0-252
            mag_gamma *= bright_8bit;                    // 0-64260
            mag_gamma /= 256;                            // 0-251
            mag_gamma *= bright_8bit;                    // 0-64005
            uint16_t pwm = mag_gamma / 16;               // 0-4000
            uint8_t ledno = by_pos[i];
            leds.setPWM(ledno, pwm);
          }

#if 1
          RotateRgb();
#else
          // This version is about 230-240 bytes, so I'm just using
          // RotateRgb().
          // This pretty much sets LED_PHASE1 to cycle^2 * bright^2,
          // scaled accordingly and in stages to prevent overflow.
          uint8_t bright15 = bright / 256;  // 0-15
          bright15 *= bright15;             // 0-225
          bright15 /= 16;                   // 0-14
          bright15 += 2;                    // 2-16
          uint16_t phase1 =
              ((display_state.joy.cycle * bright15)  // 0-4080
               / 16)                                 // 0-255
              * (display_state.joy.cycle / 8);       // 0-8128
          // Then, the sawtooth is transformed to a triangle: values
          // above the brightness become a descending value within the
          // brightness.
          if (phase1 > bright * 2)
            phase1 = bright;
          else if (phase1 > bright)
            phase1 = (bright * 2) - phase1;
          // We scale back the brightness since the RGB LED is pretty
          // bright.
          leds.setPWM(LED_PHASE1, phase1 / 4);
          // LED_PHASE2 is similar to LED_PHASE1, but uses cycle_minor.
          uint16_t phase2 =
              ((display_state.joy.cycle_minor * bright15) / 16)
              * (display_state.joy.cycle_minor / 8);
          if (phase2 > bright * 2)
            phase2 = bright;
          else if (phase2 > bright)
            phase2 = (bright * 2) - phase2;
          leds.setPWM(LED_PHASE2, phase2 / 4);
          // LED_PHASE3 roughly inverts the other two phases.
          uint16_t phase3 = bright - ((phase1 + phase2) / 2);
          leds.setPWM(LED_PHASE3, phase3 / 4);
#endif

          display_state.joy.cycle += 1;
          display_state.joy.cycle_minor -= 2;
        }
        break;

      case kSubModeCylon:
      case kSubModeCylonFill:
        {
          for (int i = 0; i < led_stars->Count(); i++) {
            float pct;
            if (joy_sub_mode == kSubModeCylon) {
              pct = 1.0 - abs(display_state.joy.phase - i);
            } else {
              pct = constrain(display_state.joy.phase - i, 0, 1);
              if (display_state.joy.direction) {
                pct = 1.0 - pct;
              }
            }
            int ledno = by_pos[i];
            leds.setPWM(ledno, LedPctToPwm(pct));
          }
          if (joy_sub_mode == kSubModeCylon) {
            display_state.joy.phase +=
                (display_state.joy.direction ? 0.6 : -0.6);
            if (display_state.joy.direction == 1 &&
                display_state.joy.phase >= led_stars->Count() - 1) {
              display_state.joy.direction = 0;
              display_state.joy.phase = led_stars->Count() - 1;
              JoyCylonHandlePhaseLed();
            } else if (display_state.joy.direction == 0 &&
                       display_state.joy.phase <= 0) {
              display_state.joy.direction = 1;
              display_state.joy.phase = 0;
              JoyCylonHandlePhaseLed();
            }
          } else {
            display_state.joy.phase += 0.6;
            if (display_state.joy.phase >= led_stars->Count() - 1) {
              display_state.joy.direction = !display_state.joy.direction;
              display_state.joy.phase = 0;
              JoyCylonHandlePhaseLed();
            }
          }
        }
        break;

      case kSubModeLast:
        // CANTHAPPEN
        break;
    }

  } else {  // PEACE and LOVE modes are handled by mostly-common code.

    RotateRgb();
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

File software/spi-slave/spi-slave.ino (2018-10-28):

#define PIN_SCLK 6
#define PIN_MOSI 7
#define PIN_NRST 8

class RisingEdge {
 public:
  bool Value(bool input);
 private:
  bool triggered = false;
};

// Only returns true if the input moves from false to true
bool RisingEdge::Value(bool input) {
  if (input == false) {
    triggered = false;
    return false;
  } else if (triggered) {
    return false;
  } else {
    triggered = true;
    return true;
  }
}

void setup() {
  Serial.begin(115200);
  pinMode(LED_BUILTIN, OUTPUT);
  digitalWrite(LED_BUILTIN, LOW);
  pinMode(PIN_SCLK, INPUT);
  pinMode(PIN_MOSI, INPUT);
  pinMode(PIN_NRST, INPUT);
}

void loop() {
  static uint8_t held_char;
  static int held_char_bits = 0;
  static RisingEdge clk_rise_detect;
  static RisingEdge rst_rise_detect;

#ifdef SHOW_BITS
  static char buf[70];
  static size_t buflen = 0;
#endif

  static bool led_rest_state = LOW;

  static unsigned long last_clk_at = 0;
  constexpr unsigned long kMinClkMicros = 800;
  bool rst = !digitalRead(PIN_NRST);
  bool rst_rise = rst_rise_detect.Value(rst);
  // Always run the clock signal through the rising edge detector,
  // even if RST is asserted, to make sure we don't lose an edge.
  bool clk = digitalRead(PIN_SCLK);
  bool clk_rise = clk_rise_detect.Value(clk);

  while (Serial.available()) {
    uint8_t byte = Serial.read();
    switch (byte) {
      case 'r':
        Serial.print(">>> RST");
        pinMode(PIN_NRST, OUTPUT);
        digitalWrite(LED_BUILTIN, HIGH);
        held_char_bits = 0;
#ifdef SHOW_BITS
        buflen = 0;
#endif
        delay(500);
        Serial.print("\r\n");
        digitalWrite(LED_BUILTIN, LOW);
        pinMode(PIN_NRST, INPUT);
        break;
      case '\r':
      case '\n':
        break;
      default:
        Serial.println(">?");
        break;
    }
  }

  if (rst_rise) {
    digitalWrite(LED_BUILTIN, HIGH);
    held_char_bits = 0;
#ifdef SHOW_BITS
    buflen = 0;
#endif
    Serial.println("*** RST");
  }
  if (rst) {
    return;
  }
  if (clk_rise) {
    unsigned long now = micros();
    if (held_char_bits && (last_clk_at + kMinClkMicros < now)) {
      //Serial.println("*** CLK");
      held_char_bits = 0;
    }
    last_clk_at = now;
    bool bit = digitalRead(PIN_MOSI);
#ifdef SHOW_BITS
    Serial.print(bit);
#endif
    held_char = (held_char << 1) | (bit ? 1 : 0);
    held_char_bits++;
    if (held_char_bits == 8) {
#ifdef SHOW_BITS
      Serial.write(' ');
      Serial.print(held_char, HEX);
      Serial.write(' ');
#endif
      switch (held_char) {
#ifdef SHOW_BITS
        // End of line characters
        case '\r':
          Serial.println("\\r");
          buflen = 0;
          break;
        case '\n':
          Serial.println("\\n\r\n");  // Make an extra line break
          buflen = 0;
          break;
#endif
        // Special control characters
        case 0:  // Noise from reusing the CLK line as a cap sensor
        case 0xff:
#ifdef SHOW_BITS
          Serial.println("----\r\n");
#endif
          break;
        case '\x0c':  // Turn LED on solid
          led_rest_state = HIGH;
          Serial.println("*** LED latched");
#ifdef SHOW_BITS
          buflen = 0;
#endif
          break;
        case '\x18':  // Turn LED to normal operation
          led_rest_state = LOW;
          Serial.println("*** LED unlatched");
#ifdef SHOW_BITS
          buflen = 0;
#endif
          break;
        // Normal characters
        default:
#ifdef SHOW_BITS
          buf[buflen] = held_char;
          buf[buflen + 1] = '\0';
          Serial.println(buf);
          buflen++;
          if (buflen >= sizeof(buf) - 2) {
            buflen = 0;
          }
#else
          Serial.write(held_char);
#endif
          break;
      }
      held_char_bits = 0;
    }
  }
  digitalWrite(LED_BUILTIN, held_char_bits ? HIGH : led_rest_state);
}

// Local Variables:
// compile-command: "~/arduino-1.8.3/arduino --upload --board arduino:avr:uno --port /dev/ttyACM0 spi-slave.ino"
// End:

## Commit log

2018-10-28 Initial commit.
    Sorry I didn't commit my drafts before this. This revision is
    destined to be named r3; the earlier revisions didn't get built. Now
    I'm getting closer to something I'd like to share. It would have been
    nice to commit my earlier revs so that people can see what the process
    was, but I just didn't have time.
    [block.scad, christmas-tree.kicad_pcb, christmas-tree.sch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]
2018-10-29 Changes made while preparing r3
    [christmas-tree.kicad_pcb, christmas-tree.sch]
2018-11-12 Change the base to a pile of presents
    [base.scad, block.scad, common.scad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]
2018-11-13 Bug fixes and debugging changes
    Remove some debugging code that forces the cap sensors to max value.
    Make the cap sense POST set the pin modes, so they can work even when the debugger has changed the pin modes.
    Fix a bug that made the blanking state only toggle once, then stay blank forever.
    Disable by default the option to cause the JOY button to always burn all LEDs.
    Move the Debugger declaration to above my own #includes, so I can use Debugger in them.
    Declare DoSanity to be a friend function of TLC5947, so it can check the pwmbuffer values; some failure modes can be detected by looking at them.
    Lower the cap sense threshold. It'll still need more tweaking, of course, especially on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
    [capsense.h, christmas-tree.ino, tlc5947.h]
2018-11-27 More changes to complete r4 of the PCB.
    Change the wreath to a new design. Export it at a higher DPI (600)
    before importing it into KiCAD; that was a big problem with the old
    rev (which had a 200 DPI export).
    Move the "Love Always" around a bit, and a few other tiny tweaks.
    No substantial changes since r3.
    Update the title blocks, silkscreened copyright notice, and metadata
    to r4.
    This revision is what's being sent out for the 26Nov18 production run;
    in other words, it's what my friends and family will get for
    Christmas. (The software will continue to be changed leading up to
    Christmas.)
    [christmas-tree.kicad_pcb, christmas-tree.sch]
2018-11-27 Add operator[] and clear() methods.
    operator[] is just for simplicity. clear() is to replace all the "=0"
    loops with a single call.
    [tlc5947.h]
2018-11-27 Add a new JOY sub-mode, tweak brightness, and shrink the executable a lot.
    CTDebugger no longer inherits from Print. The integer print routines
    now print in hex, since the Print decimal print routines take up way
    too much executable space. This saves about 1.5k.
    Add support for JOY submodes. This lets me put different display
    hacks under the JOY mode, and cycle through them by tapping on the JOY
    button repeatedly. Currently, only two sub-modes are implemented.
    Modify the minimum brightness based on field testing in different
    modes.
    Tweak the way that Peace and Love manage their gamma corrections on
    the RGB pins.
    Remove the alternate MyRandom() and just use random(). I've settled
    on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
    [christmas-tree.ino]
2018-11-27 Rename the "base" to the "stand", which is less ambiguous.
    [stand.scad]
2018-11-27 Add back some diagnostics which were previously removed for space.
    After changing CTDebugger to print in hex, I've got lots more space free.
2018-12-02 Add CTDebugger:print(float) and (double)
    These use hex representations that are similar to C++11's %a, but show
    the exponent in hex for smaller code size.
2018-12-03 Improve handling of name plaques on the stand.
    [stand.scad]
2018-12-07 Make joy_sub_mode an enum, and fix an overflow in the double-chase mode
    [christmas-tree.ino]
2018-12-08 Enable the LED test, improve the joy phase lights, cache build products
2018-12-08 Tweak the slot width a bit more
    [stand.scad]
2018-12-08 New sub-mode kSubModeCylonFill
    Make the default Joy mode kSubModeDoubleChase
    Rearrange to save a few bytes of flash here and there
    Switch kSubModeDoubleChase to use the same RGB LED driver as Peace and
    Love
    Decrease how fast BRIGHT+ and BRIGHT- taps work
2018-12-09 Adjust the compile command
    Include the progress bar during flash, and remove the path to arduino.
2018-12-11 Moved notes and parts list to the GitHub wiki
    notes.txt was moved pretty much verbatim to https://github.com/piquan/christmas-tree/wiki/Design-notes .
    parts.txt had some random notes about the parts I'm picking; I replaced it with the final BOM at https://github.com/piquan/christmas-tree/wiki/Bill-of-Materials .
2018-12-13 Improve comments on schematic
    [christmas-tree.sch]

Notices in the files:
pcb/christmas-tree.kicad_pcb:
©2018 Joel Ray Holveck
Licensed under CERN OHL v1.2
